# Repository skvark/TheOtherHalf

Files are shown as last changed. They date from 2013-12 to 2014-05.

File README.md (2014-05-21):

TheOtherHalf
============

Jolla - The Other Half 3D model (just a proto, not official)

NOTE: The models are optimized for my printer. Therefore they may not fit perfectly if printed with other printers. This includes Shapeways and other 3D printing services.

NOTE2: I have now tested the model with ABS and another printer too. Scale the models about 1 % up before printing if ABS is used because it seems to shrink more than PLA.

Printed with [Tinkerine Studio Litto](http://www.tinkerines.com/store/3d-printers/litto/) 3D printer.

Tested with these settings (PLA, close to perfect fit):

- layer resolution 0.2 mm
- first layer temp: 210 Celsius
- other layers: 185 Celsius
- fan ON at layer 4
- no skirt lines
- organic clip

Powdered sugar + water was used on top of masking tape to ensure that the first layer sticks.

Pictures (not the latest version): [3D printed other half](http://relativity.fi/jolla_toh/)

                DO WHAT THE FUCK YOU WANT TO PUBLIC LICENSE
                        Version 2, December 2004
    
     Copyright (C) 2013-2014 Olli-Pekka Heinisuo <o-p@unknownpixels.com>
    
     Everyone is permitted to copy and distribute verbatim or modified
     copies of this license document, and changing it is allowed as long
     as the name is changed.
    
                DO WHAT THE FUCK YOU WANT TO PUBLIC LICENSE
       TERMS AND CONDITIONS FOR COPYING, DISTRIBUTION AND MODIFICATION
    
      0. You just DO WHAT THE FUCK YOU WANT TO.

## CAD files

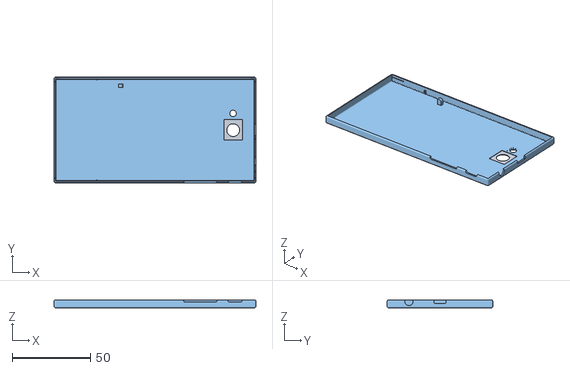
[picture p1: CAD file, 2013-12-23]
theotherhalf.stl
129.3 x 67.6 x 5.05

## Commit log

2013-12-09 fixed usb, 3.5mm plug and camera/flash places and added cuts for lock/power/sound buttons,
    [theotherhalf.stl]
2013-12-21 little fixes for button/usb cutout locations
    [theotherhalf.stl]
2013-12-23 should fit now perfectly when printed on layer resolution 0.2mm, made multiple minor changes to cutout locations
    [theotherhalf.stl]
2014-03-05 added the Power Half :)
